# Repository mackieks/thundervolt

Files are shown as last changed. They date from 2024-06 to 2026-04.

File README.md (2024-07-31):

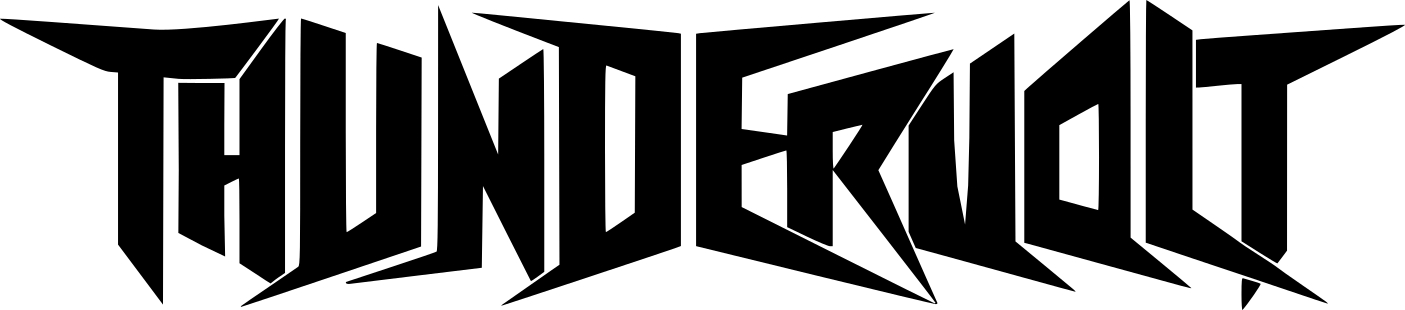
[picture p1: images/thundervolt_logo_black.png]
<picture> <source media="(prefers-color-scheme: dark)" srcset="images/thundervolt_logo_white.png">  </picture> 

Thundervolt is a suite of open-source hardware and software that enables software-configurable undervolting of 4-layer Wiis. 

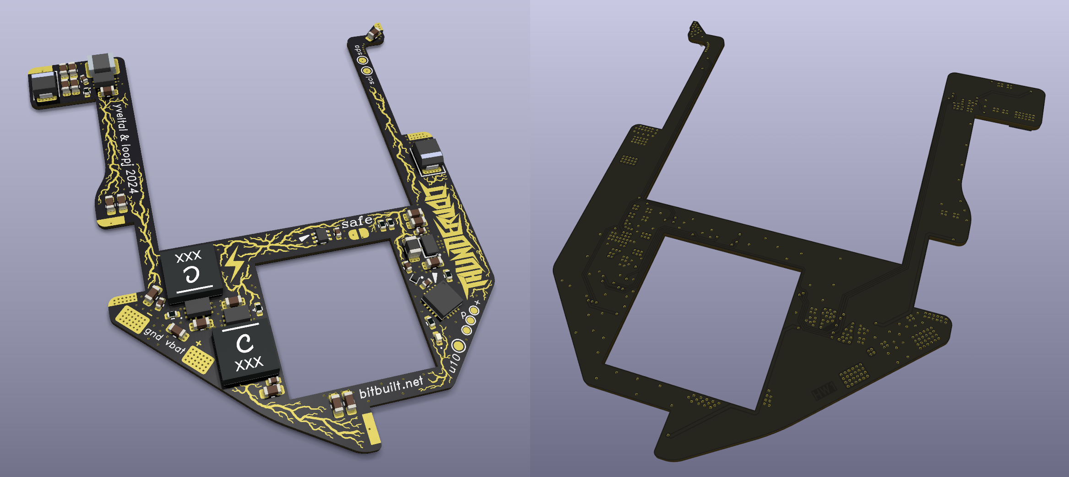
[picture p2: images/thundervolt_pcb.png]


The Thundervolt PCBs (Thundervolt 1 and Thundervolt Lite shown) are stylish, highly-integrated power hats for 4-layer Wiis that solder directly to the Wii motherboard. Only 3 wires are necessary to connect Thundervolt to the Wii (I2C and Reset). Power is supplied via two additional wires.

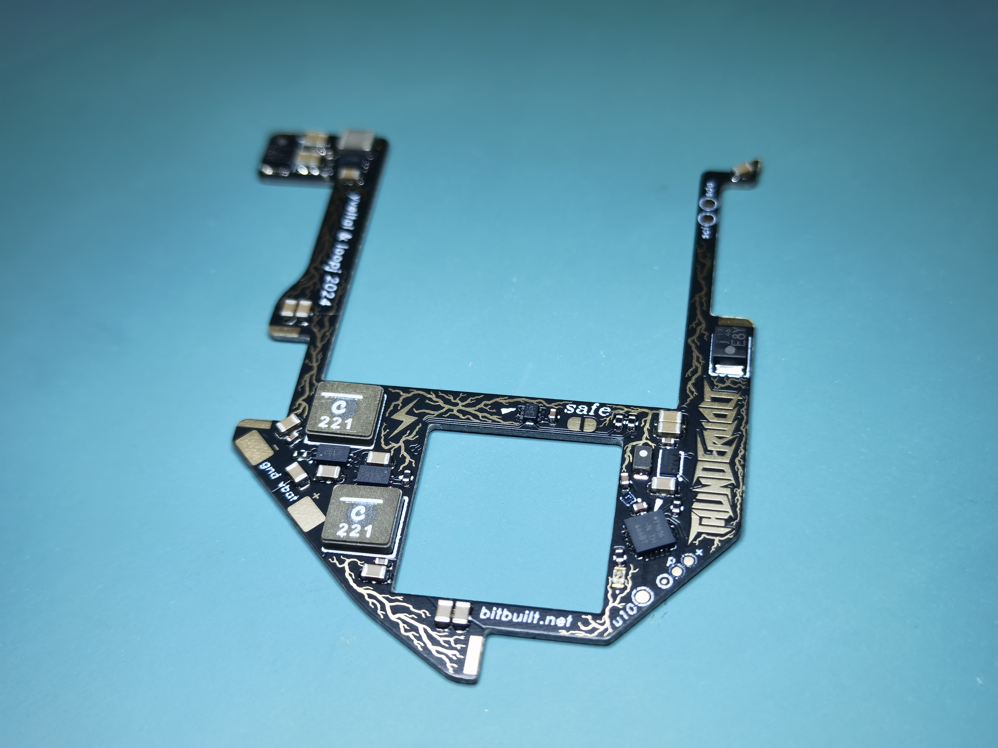
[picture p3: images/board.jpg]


The Thundervolt homebrew app (Dolphin debug version shown) provides granular control over each voltage regulator on the Thundervolt board, as well as emergency overtemperature protection with a configurable threshold. 

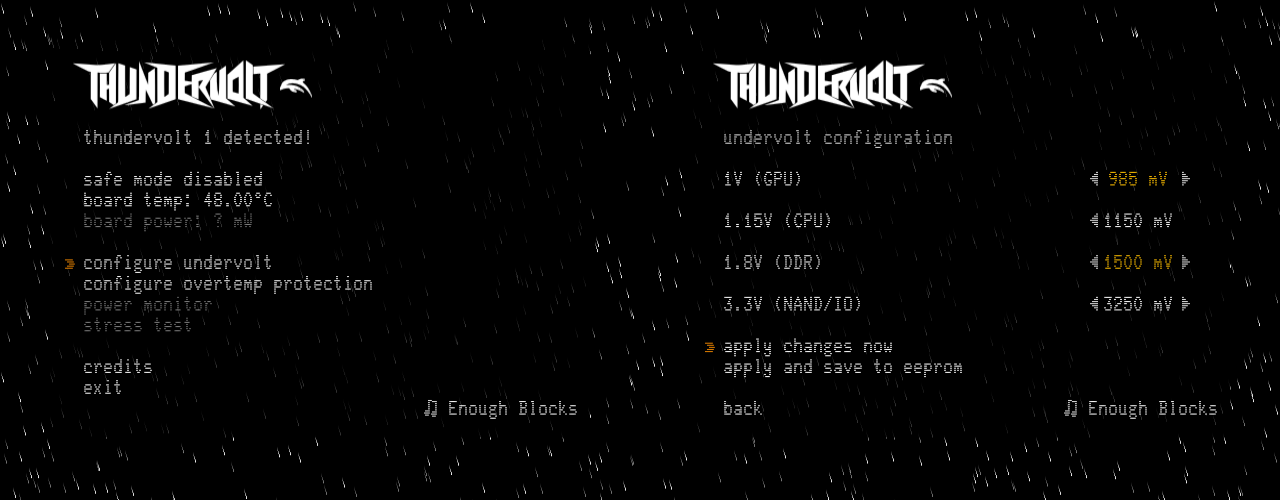
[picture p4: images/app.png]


Users can apply changes live, and save settings to Thundervolt's EEPROM for persistence across reboots. 

More functionality such as CPU/GPU/MEM stress tests and a power monitor for Thundervolt 2 will be added to the app in the future.

## Features
- 0.8mm 4L rigid PCB — solders directly to 4-layer Wii motherboards
- 55 x 47mm — fits within all but the most extreme trim outlines
- 2.4V to 5.5V input (intended for 1S li-ion or 5V USB-C)
- Highly efficient I2C-controlled buck regulators for 1V, 1.15V, and 1.8V (η > 90%)
- Highly efficient I2C-controlled buck-boost regulator for 3.3V (η > 90%)
- Dynamic undervolting, configurable via Wii homebrew app
- Safe mode solder jumper to force stock voltages
- Wii power-on reset functionality (aka U10 emulation)
- Onboard TMP1075N for temperature monitoring and emergency overtemp shutdown
- Integrated INA700s for realtime voltage/current/power monitoring (Thundervolt 2 only)

## What Thundervolt does NOT do
- Battery management and charging
- Fan control
- Power button handling for portables
- USB PD negotiation

Adding a full BMS to Thundervolt would require major sacrifices to regulator efficiency, thermal performance, and cost. A companion board called *Mjolnir* is in development to fulfill these needs, and will feature tight integration with the existing Thundervolt ecosystem.

## Ordering & Assembly

See [the hardware folder](https://github.com/mackieks/thundervolt/tree/main/hardware) for details on ordering and [assembling](https://github.com/mackieks/thundervolt/blob/main/hardware/ASSEMBLY.md) Thundervolt PCBs.

## Usage
The homebrew app is pretty self explanatory; see [the demo on YouTube](https://youtu.be/DeZFMLoE9EQ) for details. A full writeup will come later.

## Credits

Thundervolt hardware designed by YveltalGriffin

Thundervolt firmware by loopj

Thundervolt homebrew by:
- YveltalGriffin (UI, app)
- loopj (I2C, app)
- Alex/supertazon (graphics)
- ShockSlayer (music)

## License

Thundervolt hardware is licensed under Solderpad Hardware License v2.1.

Thundervolt software (firmware + homebrew) is provided under The MIT License.

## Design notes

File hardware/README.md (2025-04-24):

<picture> <source media="(prefers-color-scheme: dark)" srcset="../images/thundervolt_logo_white.png">  </picture> 

There are 3 variants of the Thundervolt PCB. As of 2024-07-07, **Thundervolt Lite** and **Thundervolt 1** have been released.
- **Thundervolt Lite**
  - A low cost revision of the original design with **identical functionality** to Thundervolt 1. It does not require VIPPO and only costs $7 for 10 bare boards!
  - Thundervolt Lite is easier to assemble and easier to solder to the Wii motherboard.
  - Fully tested and released to the public! This folder contains the KiCAD source and Gerbers.
- **Thundervolt 1**
  - The original design, with software-controlled undervolting and temperature sensing. It requires a [VIPPO/POFV PCB](https://jlcpcb.com/blog/32-Free-Via-in-Pad-on-6-20-Layer-PCBs-with-POFV) which is rather expensive ($10 per bare board).
  - Fully tested and released to the public! This folder contains the KiCAD source and Gerbers.
- **Thundervolt 2**
  - The Lamborghini of Wii voltage regulation. Thundervolt 2 includes four INA700 power monitor ICs and can report the Wii's current and power consumption in real time. It requires an even higher spec PCB than Thundervolt 1 and is quite expensive ($14-$20 per bare board)
  - Currently unreleased — still in testing

- All Thundervolt revisions require placing and reflowing at least one chipscale BGA (the TPS63810 3.3V buck-boost regulator). 
- Thundervolt 1 and 2 require placing and reflowing an additional chipscale part (LP5907UVX-1.8, 0.7x0.7mm) and have tighter component spacing than Lite. 
- Thundervolt 2 also requires placing four additional chipscale BGAs (INA700, 1.2x1.3mm)
- Thundervolt Lite is the easiest to assemble. Thundervolt 1 is tougher, and Thundervolt 2 is the most challenging. Magnification is highly recommended for assembling all variants.

Two jig PCBs for solderpaste stenciling are also provided. Order both jigs as 2-layer 0.8mm boards.



## Ordering PCBs

### Thundervolt Lite

Recommended board fabrication specs for **Thundervolt Lite** (JLCPCB).

**MANDATORY**
- 0.8mm 4-layer rigid PCB
- Tented or plugged vias
- Min via hole size/diameter: leave at default. Thundervolt Lite has large vias that do not incur additional charges.

Optional
- ENIG (improves solderability for chipscale BGAs)
- 1oz/in² copper on internal layers - not necessary, but technically improves PDN performance (imperceptible to end user)
- Black soldermask - not necessary, but looks great with the lightning bolt art :)

In the **Remark** section of your Thundervolt Lite PCB order, paste the following comment:
```
Kindly note that the graphics on the fMask layer are for aesthetics. Please do NOT edit any of the fMask apertures on the board, or remove any thin soldermask webs. Thank you!
```

If JLC tries to upcharge you for the soldermask artwork, push back. The artwork requires zero additional work or intervention on their part. Feel free to reference my Thundervolt Lite order number if necessary: **Y118-2549677A**

### Thundervolt 1

Recommended board fabrication specs for **Thundervolt 1** (JLCPCB). Thundervolt 1 is a high-spec PCB. Please read this entire section so you understand the fab requirements. 

**MANDATORY**
- 0.8mm 4-layer rigid PCB
- Epoxy Filled & Capped vias (aka VIPPO or POFV)
- Min via hole size/diameter: 0.15mm/(0.25/0.3mm)

Optional
- ENIG (improves solderability for chipscale BGAs)
- 1oz/in² copper on internal layers - not necessary, but technically improves PDN performance (imperceptible to end user)
- Black soldermask - not necessary, but looks great with the lightning bolt art :)

In the **Remark** section of your Thundervolt 1 PCB order, paste the following comment:
```
Kindly note that the graphics on the fMask layer are for aesthetics. Please do NOT edit any of the fMask apertures on the board, or remove any thin soldermask webs. Thank you!
```

If JLC tries to upcharge you for the soldermask artwork, push back. The artwork requires zero additional work or intervention on their part. Feel free to reference my Thundervolt 1 order number if necessary: **Y108-2549677A**

**Note:** Check the box for **Confirm Production File**. Then check the box for "Do Not Confirm Automatically." JLCPCB will often edit the gerbers in unpleasant ways and you **must** push back on this. If they change the via drill sizes, you need to request that they abide by their listed spec of 0.15mm drills. 

A comment like this when reviewing the production file goes a long way:
```
In the production file, the via drill size has been changed from 0.15mm to 0.2mm [or whatever they changed it to]. Please do not change the via size. They should be 0.15mm drill and 0.3mm diameter as in the original file. I greatly appreciate your assistance with this. Thanks!
```

Some amount of "compensation" (growth of annular rings + padshaving) is unavoidable; however, if the drills are increased to 0.2mm or more, this will result in extreme padshaving of many vias/traces. You'll also notice that they expand the copper clearance around drills on inner layers as part of the compensation process. As long as they are not changing the drill diameters, this is OK. They may also request to remove annular rings ("pads") on internal layers. This is OK as it lessens the impact of their copper clearance expansion on the inner planes.



## Stencil and Jig

Both an electropolished solder paste stencil and the two jig PCBs (jig1, jig2) are **highly** recommended for assembly. 

**MANDATORY STENCIL SPECS**
- Custom dimensions: **90 x 90mm**
- Top only
- Electropolishing

Order both jig1 and jig2 as 0.8mm 2-layer PCBs. In the **Remark** section of both jig PCB orders, paste the following comment:
```
Please note that this is a mechanical PCB and does not contain any drill holes or soldermask openings. Thank you!
```

## BOM

**Thundervolt Lite:** [Link to Mouser cart with BOM](https://www.mouser.com/ProjectManager/ProjectDetail.aspx?AccessID=3CC491924A) [Link to Digikey cart with BOM](https://www.digikey.com/en/mylists/list/P9BJON8540)

**Thundervolt 1**: [Link to Mouser cart with BOM](https://www.mouser.com/ProjectManager/ProjectDetail.aspx?AccessID=D2F0182832)

**Note:** The 0412CDMCCDS-R22MC low-profile inductors used on Thundervolt Lite are only available [from Digikey.](https://www.digikey.com/en/products/detail/sumida-america-inc/0412CDMCCDS-R22MC/11682034)

**Note:** The XFL5015-221MEC low-profile inductors used on Thundervolt 1 and Thundervolt 2 are only available [directly from Coilcraft.](https://www.coilcraft.com/en-us/products/power/shielded-inductors/molded-inductor/xfl/xfl501x/xfl5015-221/)

## Assembly

See [ASSEMBLY.md](https://github.com/mackieks/thundervolt/blob/main/hardware/ASSEMBLY.md) for assembly instructions.

## License

Thundervolt hardware was designed by YveltalGriffin and is licensed under Solderpad Hardware License v2.1.

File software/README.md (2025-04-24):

# Thundervolt Software

Firmware and homebrew for Thundervolt.

Pre-built binaries for the firmware, and packages for the homebrew can be found in the [releases](https://github.com/mackieks/thundervolt/releases) section.

## Firmware

The Thundervolt firmware is written in AVR C with no external dependencies. We use [PlatformIO](https://platformio.org/) to build and flash the firmware, providing a consistent build environment and an easy way to manage toolchains.

### Prerequisites

- [PlatformIO Core](https://platformio.org/install) installed.
- UPDI programmer (e.g., [ATMEL-ICE](https://www.microchip.com/en-us/development-tool/atatmel-ice), [Adafruit UPDI Friend](https://www.adafruit.com/product/5879), [SerialUPDI](https://www.tindie.com/products/mcudude/serialupdi-programmer/)).

### Building

To build the firmware using PlatformIO, enter the `firmware` directory and run:

```bash
pio run -e thundervolt-hw1
```

This will automatically download the required toolchain and build the firmware.

If you are using VS Code, you can build the firmware by opening the `firmware` folder in VS Code. Let the PlatformIO extension configure the project. Select the correct environment to match your board variant. Then click the Build button at the bottom (check mark icon).

### Flashing

Flashing the firmware requires a UPDI programmer. You can use the official [ATMEL-ICE](https://www.microchip.com/en-us/development-tool/atatmel-ice), or a cheaper programmer such as the [Adafruit UPDI Friend](https://www.adafruit.com/product/5879) or MCUdude's [SerialUPDI](https://www.tindie.com/products/mcudude/serialupdi-programmer/).

You need to change line 12 of `platformio.ini` to match the programmer you're using.

- `atmelice_updi` for ATMEL-ICE
- `serialupdi` for SerialUPDI or UPDI Friend

Then click the Upload button in VS Code. 

To flash the firmware directly using PlatformIO, run:

```bash
pio run -e thundervolt-hw1 -t upload
```

Ensure your UPDI programmer is connected before running the command or clicking the Upload button! All Thundervolt board variants have the same programming pad pinout, but you'll need to reference your specific programmer's docs for its pinout. 

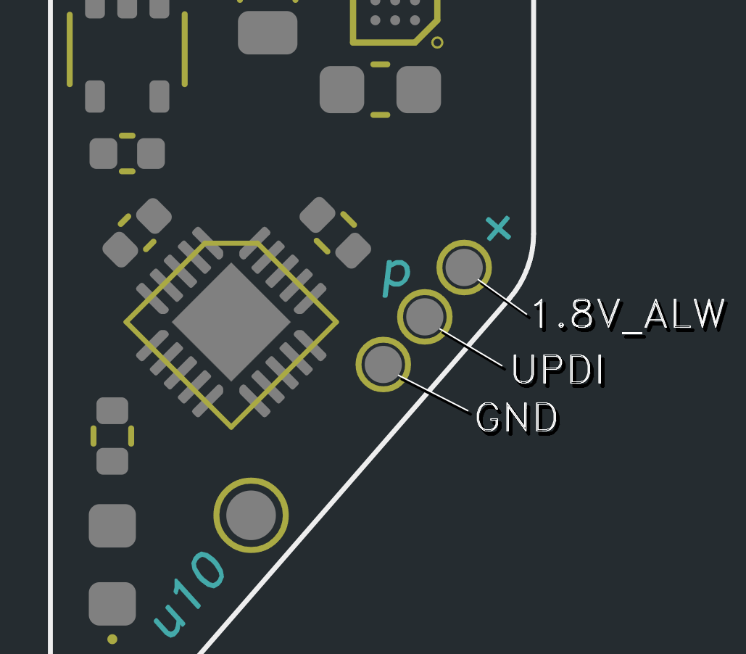
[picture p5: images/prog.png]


The Thundervolt board must be powered from a 2.5V - 5.5V supply for programming to succeed! See [ASSEMBLY.md](https://github.com/mackieks/thundervolt/blob/main/hardware/ASSEMBLY.md) for details.

## Homebrew

The Thundervolt homebrew is a standard Wii homebrew, built with [devkitPro](https://devkitpro.org/). It depends on [GRRLIB](https://github.com/GRRLIB/GRRLIB).

### Prerequisites

- [devkitPro](https://devkitpro.org/wiki/Getting_Started) installed.
- [GRRLIB](https://github.com/GRRLIB/GRRLIB) installed.

### Building

To build the homebrew, enter the `homebrew` directory and run:

```bash
make
```

This will create a `thundervolt.dol` file.

### Packaging

To build a zip package of homebrew and assets, run:

```bash
make dist
```

The zip package will be created in the `dist` directory.

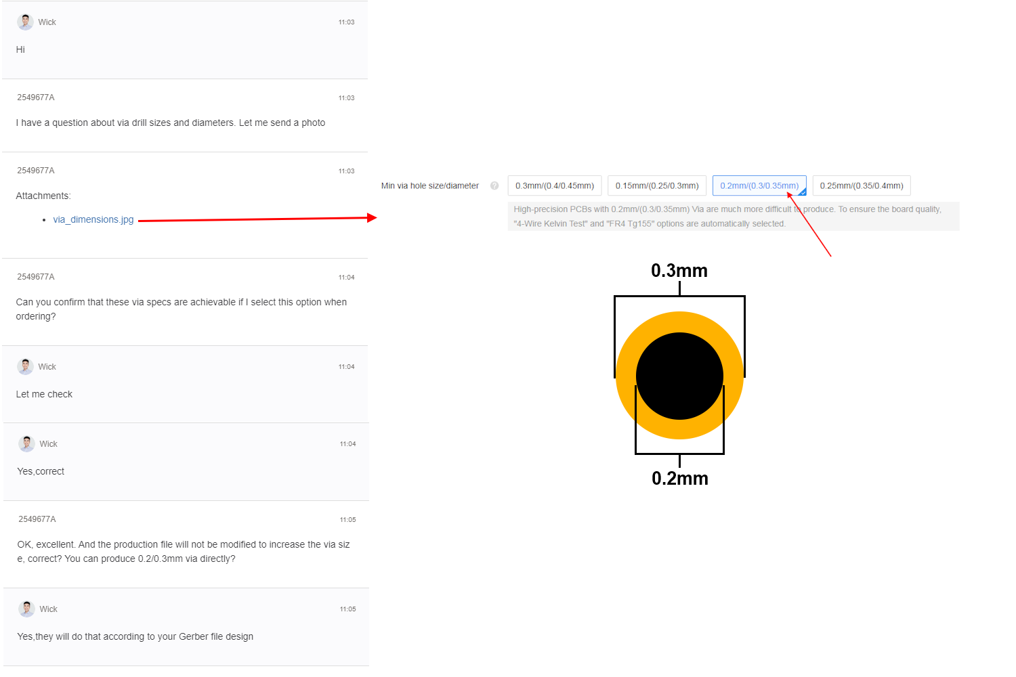
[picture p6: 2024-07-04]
images/jlc_support.png

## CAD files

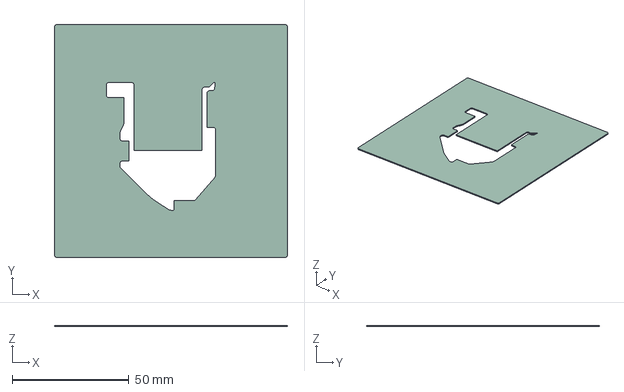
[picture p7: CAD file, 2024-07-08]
hardware/KiCad/jig1/jig1.step
100.0 x 100.0 x 0.6 mm

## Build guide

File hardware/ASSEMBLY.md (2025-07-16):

# Assembly

## Supplies & Equipment

Before assembling a Thundervolt, you should have the following supplies:
- Thundervolt PCB
- Two jig PCBs (outer and inner)
- Electropolished solderpaste stencil
- Solder paste
  - Recommendations: [TS391AX](https://www.mouser.com/ProductDetail/Chip-Quik/TS391AX?qs=1mbolxNpo8ei%252BndH51pRbA%3D%3D) (leaded), [GC50](https://www.digikey.com/en/products/detail/loctite/2591111/12570372) (lead-free)
- Solder paste spreader
  - Recommendation: [SS-METAL-0.2-68X36](https://www.mouser.com/ProductDetail/Chip-Quik/SS-METAL-0.2-68X36?qs=By6Nw2ByBD2Amr8PPfSm%252Bg%3D%3D)
- [Fine tweezers](https://www.mouser.com/ProductDetail/Apex-Tool-Group/EROP3SA?qs=AGa1uUH1LDimyk4IzeBO0g%3D%3D) or a vacuum pen ([Pixel Pump](https://shop.robins-tools.com/products/pixel-pump-starter-kit), [Pick+](https://shop.randomhacks.pt/products/pick)) for component placement
- Reflow method
  - Hot plate: [UYUE 946-1010 or UYUE 946C  ](https://www.aliexpress.us/item/3256804722742113.html)
  - Reflow oven: [Controleo3](https://whizoo.com/collections/controleo3)
  - Hot air is **not** recommended for assembly as it will blow the chipscale BGAs away!
- Hot air station ([1](https://www.aliexpress.us/item/3256801112464148.html), [2](https://www.aliexpress.us/item/2255800796511424.html)), soldering iron ([1](https://pine64.com/product/pinecil-smart-mini-portable-soldering-iron/), [2](https://www.aliexpress.com/i/3256802537430044.html), [3](https://hakkousa.com/fx-951-soldering-station.html)) for rework
- Tacky flux for rework ([SMD291](https://www.mouser.com/ProductDetail/Chip-Quik/SMD291?qs=8BX3xQzFIvmwkympZqnNNA%3D%3D), [MG Chem 8341](https://www.mouser.com/ProductDetail/MG-Chemicals/8341-10ML?qs=SUQPjvP5usWRLDN27VlqNg%3D%3D), [AMTECH NC-559-V2](https://shop.inventec.dehon.com/products/copie-de-amtech-nc-559-v2), [CitriFlow](https://www.injuredgadgets.com/tcrs-citriflow-tm-no-clean-tacky-flux-paste-w-needle-and-cover-10g-syringe/))

Nice-to-haves:
- [Magnetic surface](https://www.ebay.com/itm/186036507277) to stencil on
- Nd magnets and double-sided tape for stenciling
- [91% isopropyl alcohol](https://www.ebay.com/itm/363216561079) for cleaning
- [Kimwipes](https://www.mouser.com/ProductDetail/MG-Chemicals/830-34155?qs=WXzVXFlun0Vx2RYSUZAAsA%3D%3D)
- [Ultrasonic cleaner](https://www.amazon.com/VEVOR-Commercial-Ultrasonic-Capacity-Solution/dp/B01HGNM5WE)
- Magnification is **strongly** recommended
  - [Magnifying Lamp](https://www.amazon.com/Brightech-LightView-PRO-Magnifying-Magnification/dp/B016LTTS8S/)
  - [Amscope 7x-45x](https://www.ebay.com/itm/140938262240)

## Assembly

Once you have everything you need, you can begin stenciling. Apply some double-sided tape to the back of the outer jig PCB.

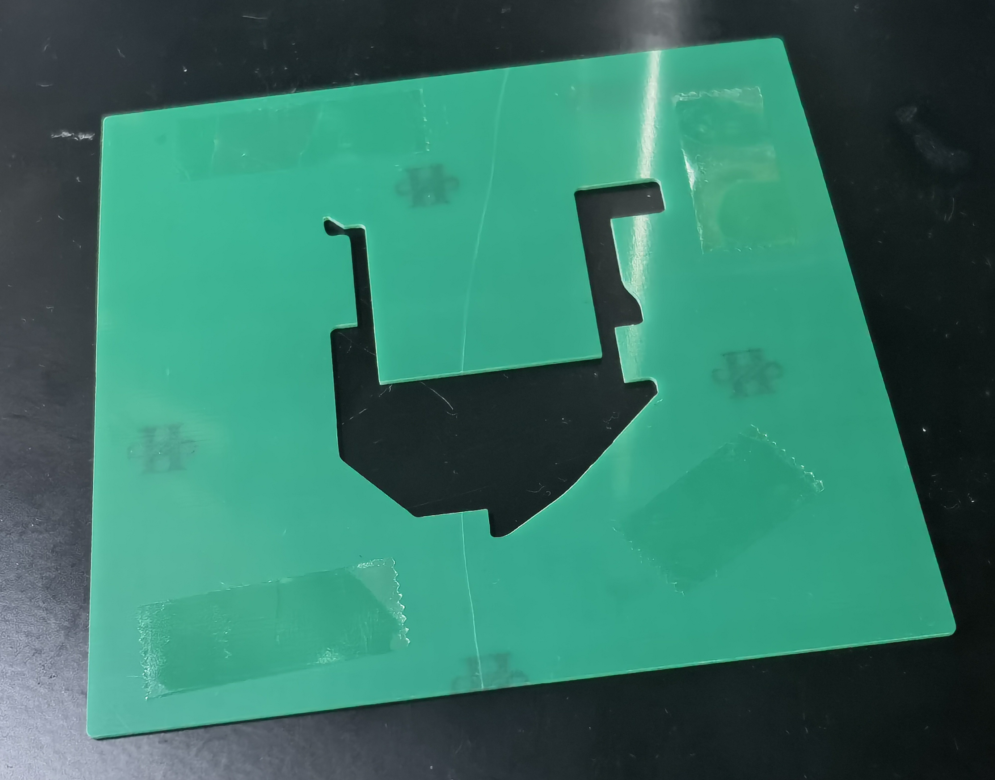
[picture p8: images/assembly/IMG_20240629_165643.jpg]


Adhere the jig to your stenciling surface.

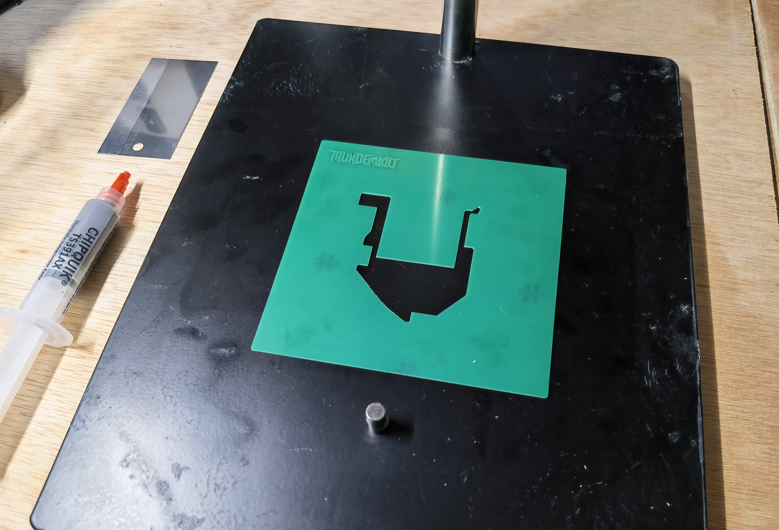
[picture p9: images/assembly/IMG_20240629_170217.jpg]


Prep the Thundervolt PCB by cleaning it with isopropyl alcohol. Then insert the Thundervolt PCB and inner jig into the outer jig.

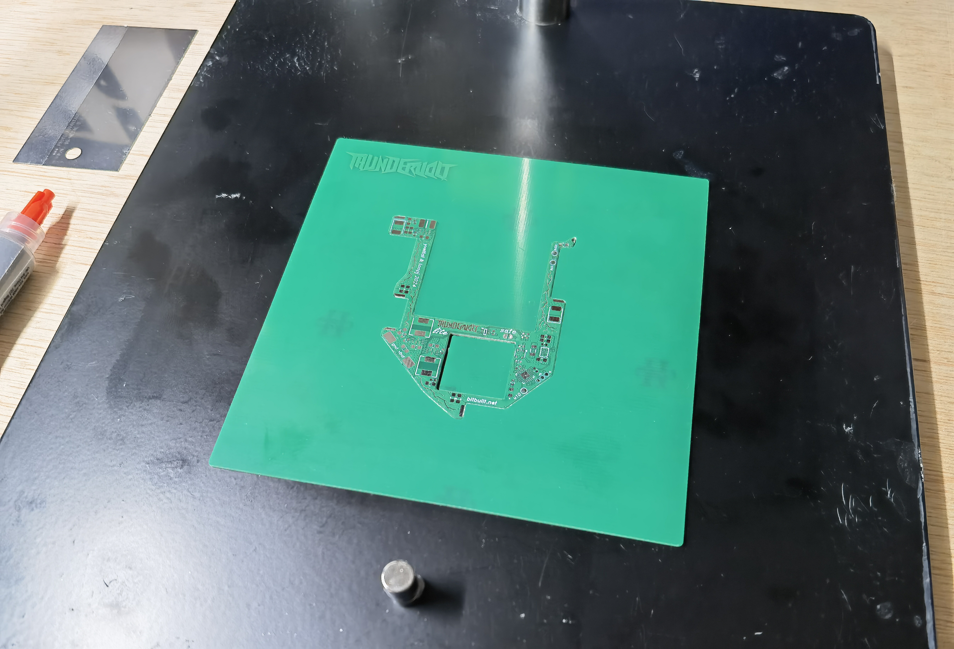
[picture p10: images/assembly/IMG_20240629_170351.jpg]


Prep the stencil by cleaning it with isopropyl alcohol.

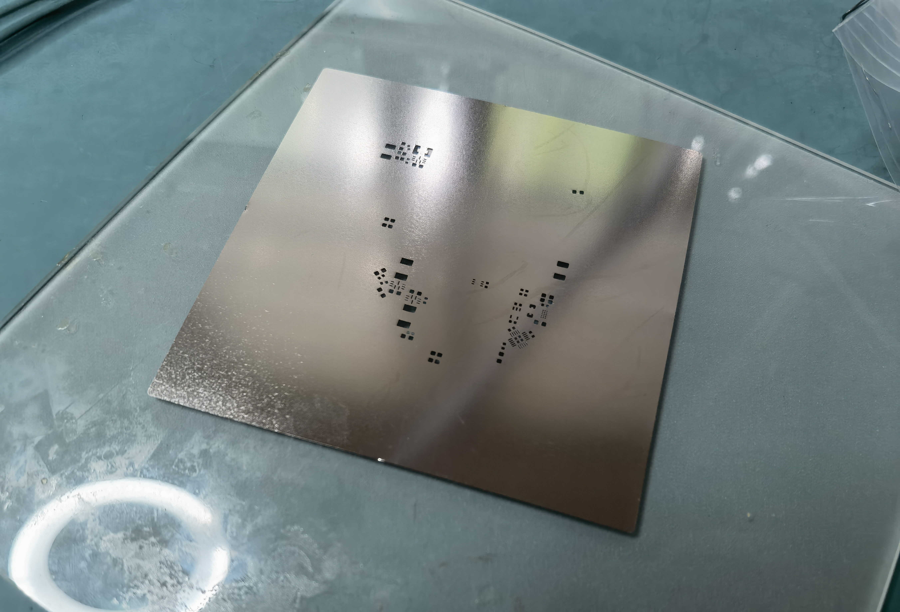
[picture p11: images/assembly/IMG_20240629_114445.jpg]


Align the stencil with the Thundervolt PCB. Make sure the stencil apertures align perfectly with the exposed pads on the board— good lighting is critical here. Use some tape at the top edge of the stencil to secure it in place and act as a hinge. If you are using a magnetic stenciling surface, you can place some strong magnets on the edges of the stencil to keep it flush.

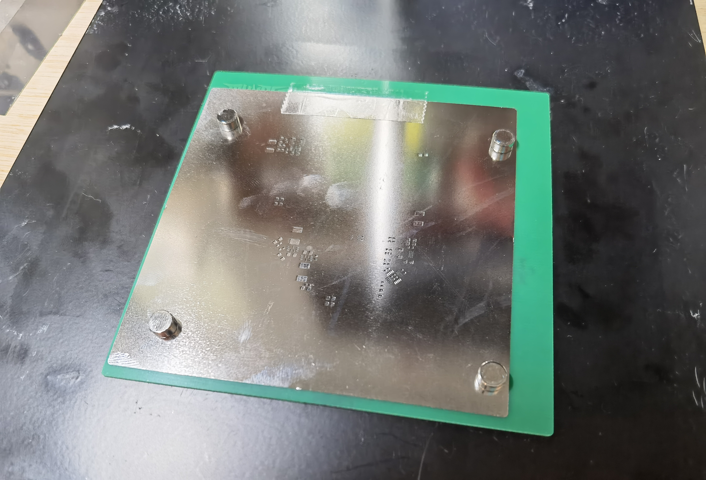
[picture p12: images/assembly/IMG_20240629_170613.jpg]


Dispense some solderpaste in a line across the top edge of the stencil and squeegee it downward. There are many tutorials for stenciling on YouTube if you need additional guidance.

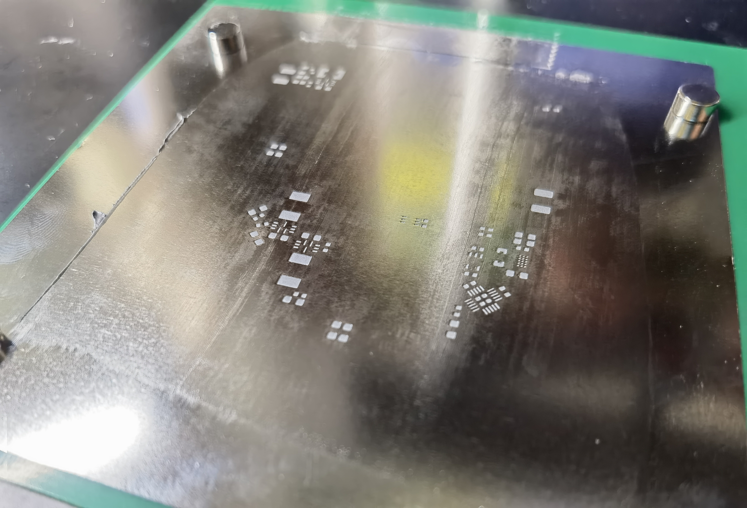
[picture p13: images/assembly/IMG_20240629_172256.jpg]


Carefully slide the magnets off the stencil and peel it up. The cleaner your pasting and stencil release, the less rework you will have to perform after reflow. It's worth retrying the process a couple times to get it right.

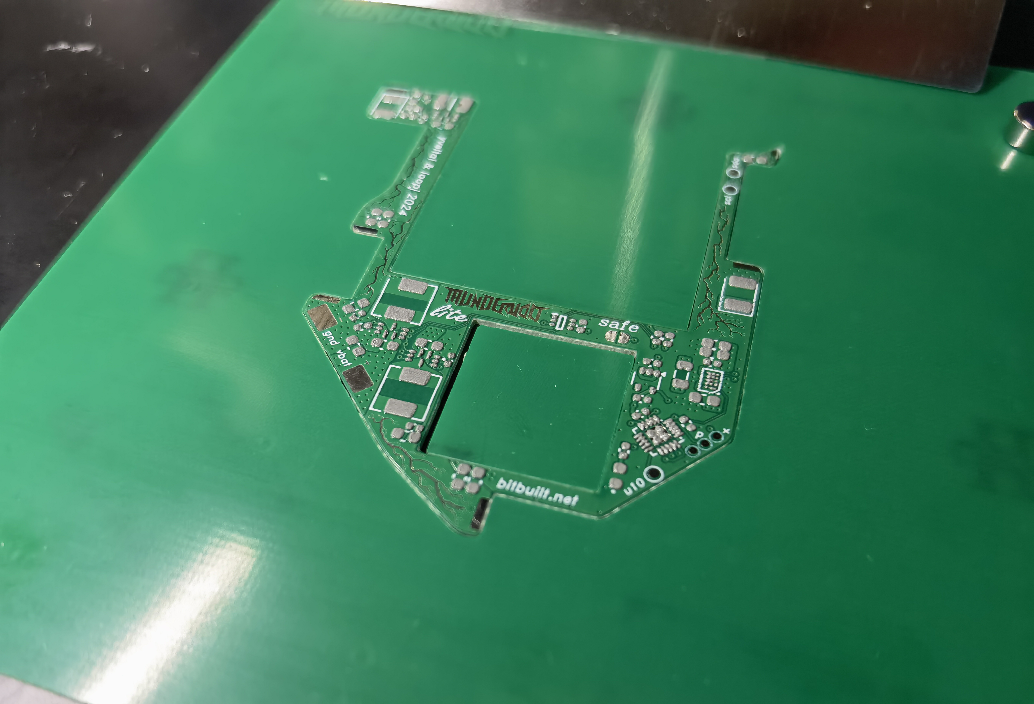
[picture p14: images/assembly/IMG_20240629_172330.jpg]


Open the BOM.html file for your Thundervolt variant in a web browser and place all the components with tweezers or a vacuum pen.



Reflow the PCBA. A hot plate works well for one-offs. Otherwise, use a reflow oven. Hot air is **not** recommended for reflow as it tends to blow the chipscale BGAs away.

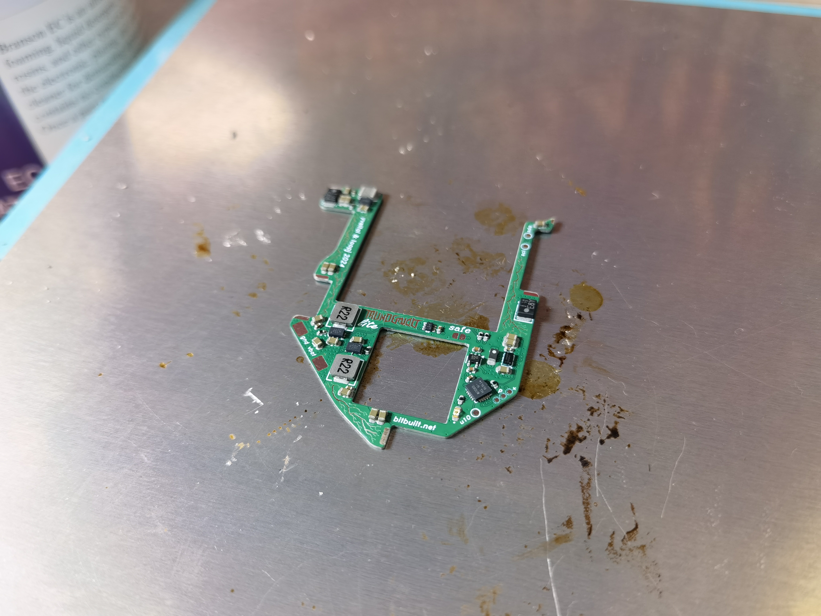
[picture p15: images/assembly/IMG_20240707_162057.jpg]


## Rework

You may need to perform rework on your Thundervolt board, especially if your board was sitting out for a long time, or your pasting job was messy (both of which were true for this example assembly!) Inspect the board for any misaligned or tombstoned components, and any head-in-pillow defects. Any free-floating solder balls should also be removed.



Drowning components in tacky flux and reflowing them with hot air solves most issues. Sometimes you need to remove a component, re-tin the pads on the PCB with your iron, and reflow the part back on. 

After rework, clean off all flux residue with Kimwipes and 91% isopropyl or an ultrasonic cleaner. Inspect all the solder joints, especially on the voltage regulators and BGAs. 





Check for shorts between GND and the following nets: VBAT, 1.8V_ALW, LX1/LX2 on the 3.3v regulator, and the output rails. Also check for shorts between EN (non-GND side of R7) and VBAT/LX1/LX2/3.3V. (LX1 and LX2 are the two pins of L4.)

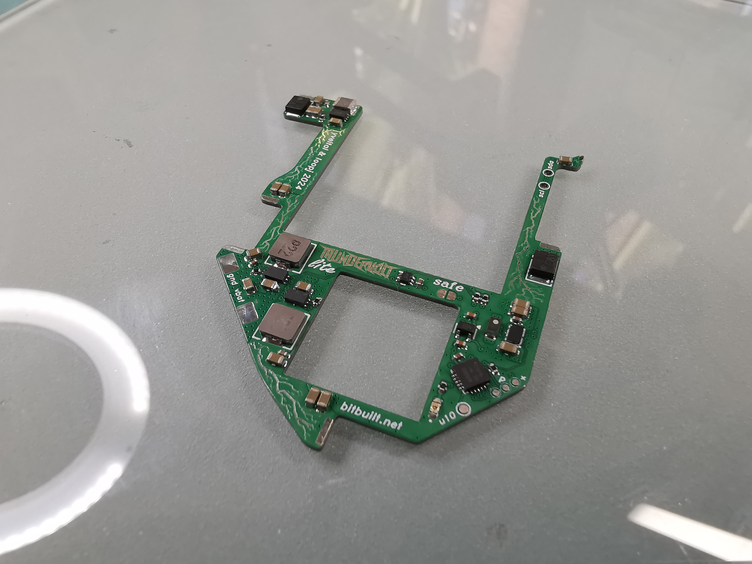
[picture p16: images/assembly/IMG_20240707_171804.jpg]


## Bring-Up

Once the board is fully assembled and cleaned, you can flash it. Congrats!



Thundervolt must be powered from the VBAT and GND pads in order to be flashed! Connect a 2.5V - 5.5V supply (or 1S li-ion battery) to VBAT and GND. Measure voltage between 1.8V_ALW and GND at the programming pads to confirm the LDO is outputting 1.8V.

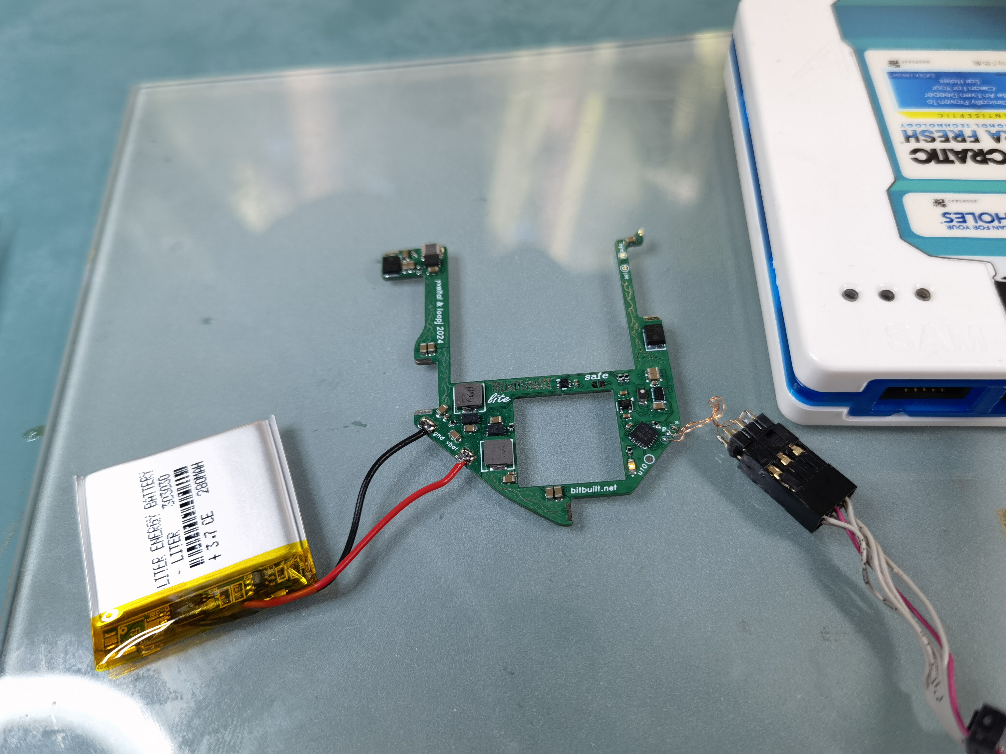
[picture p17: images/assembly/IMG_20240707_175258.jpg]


Now you can connect your programmer to the programming pads and flash the latest Thundervolt firmware. Be sure to build and flash the firmware matching your board type.

All board variants have the same programming pad layout. Reference your programmer's docs for its pinout.



See the [software folder](https://github.com/mackieks/thundervolt/tree/main/software) for more details on building and flashing the firmware.

## Troubleshooting

Once the firmware is flashed, Thundervolt automatically does a self-test.  If everything is OK, the amber LED will pulse slowly (breathing pattern). If the ATtiny cannot talk to all of the regulators and the temperature sensor over I2C, it will turn off the regulators and flash the amber LED with an SOS pattern. This indicates an assembly issue on the board.

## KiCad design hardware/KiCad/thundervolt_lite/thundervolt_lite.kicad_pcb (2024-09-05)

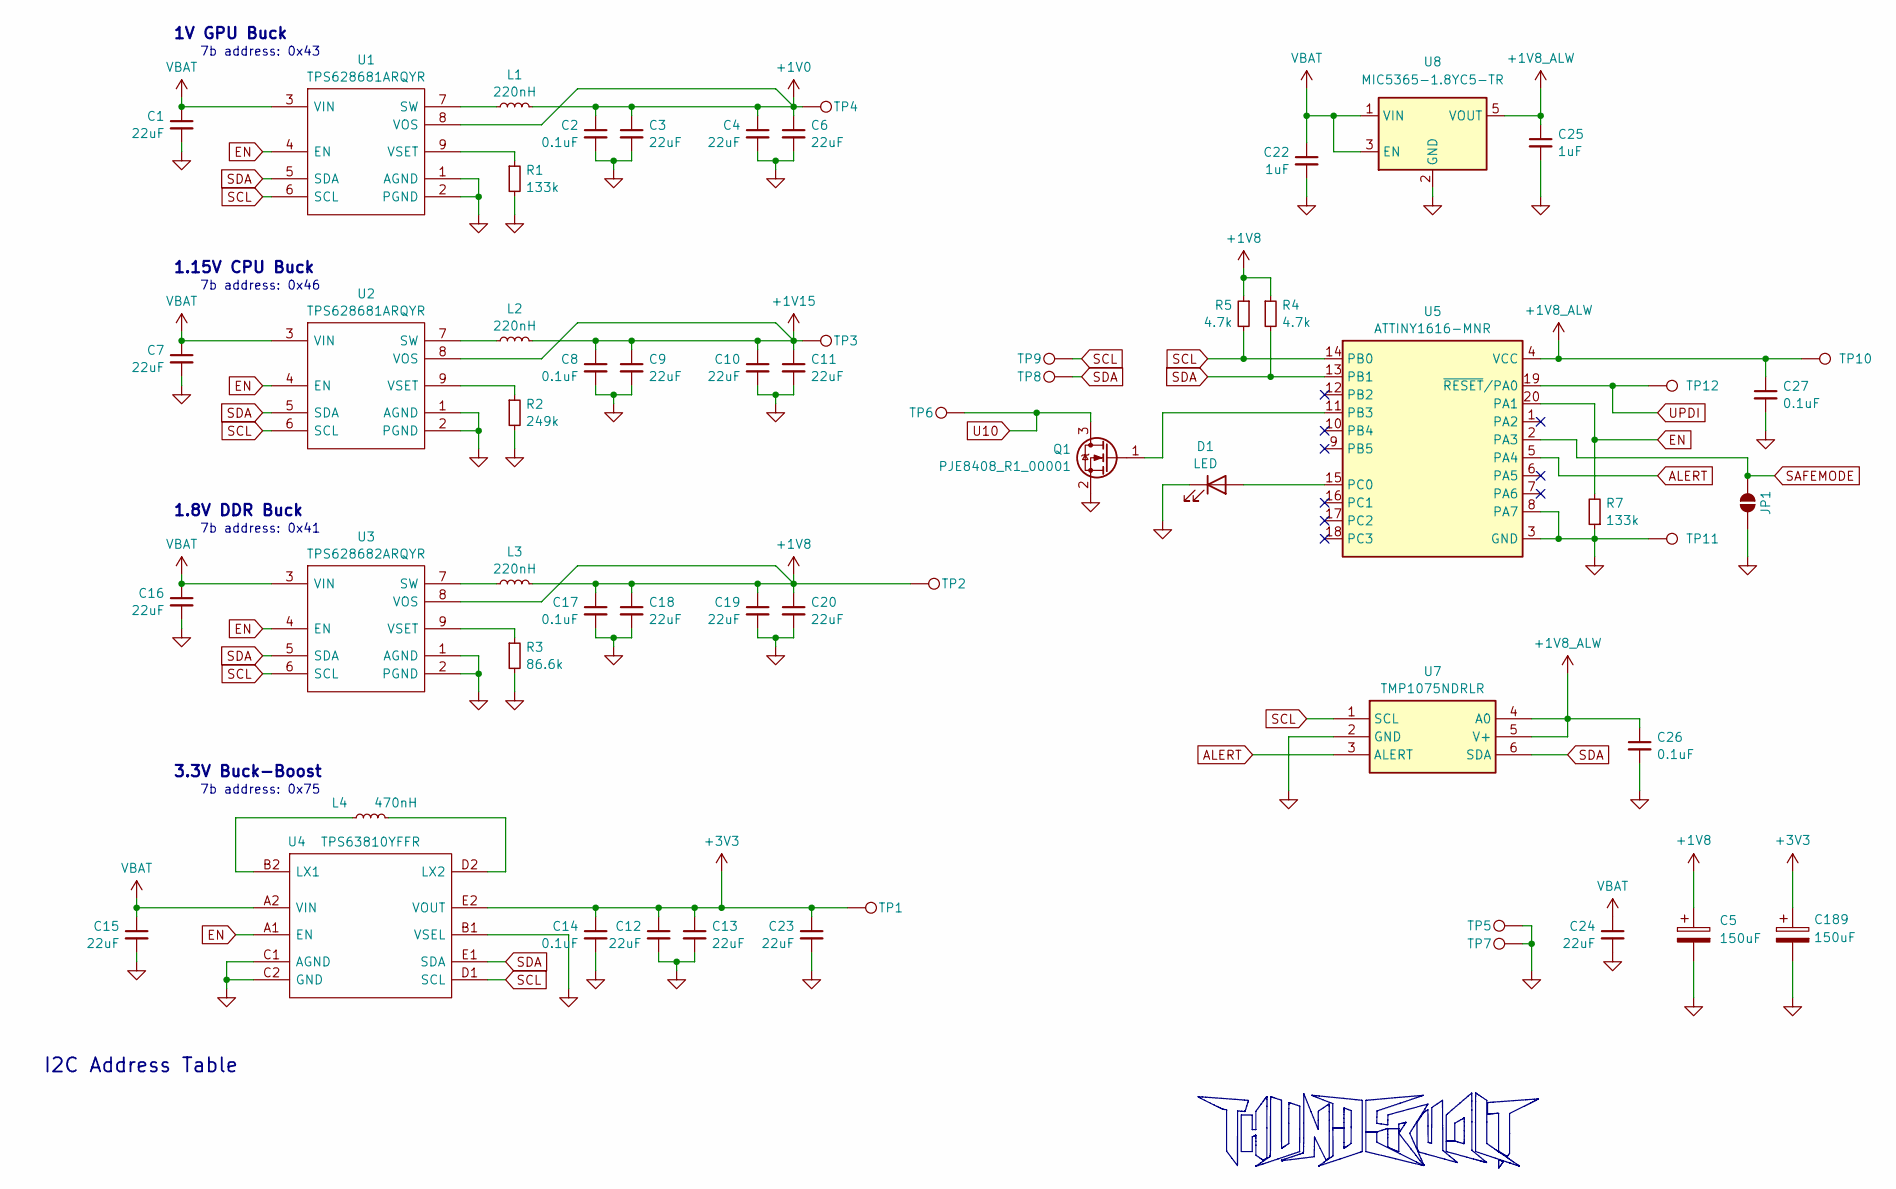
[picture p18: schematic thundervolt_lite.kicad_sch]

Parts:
C1, C3, C4, C6, C7, C9, C10, C11, C12, C13, C15, C16, C18, C19, C20, C23, C24: 22uF; C_0603_1608Metric
C2, C8, C14, C17, C26, C27: 0.1uF; C_0402_1005Metric
C5, C189: 150uF; CP_EIA-3528-15_AVX-H
C22, C25: 1uF; C_0402_1005Metric
D1: LED; LED_0603_1608Metric
JP1: SolderJumper_2_Open; SolderJumper-2_P1.3mm_Open_RoundedPad1.0x1.5mm
L1, L2: 220nH; 0412CDMCCDS-R22MC
L3: 220nH; INDC3225X120N
L4: 470nH; L_0805_2012Metric
Q1: PJE8408_R1_00001; SOT-523
R1, R7: 133k; R_0402_1005Metric
R2: 249k; R_0402_1005Metric
R3: 86.6k; R_0402_1005Metric
R4, R5: 4.7k; R_0402_1005Metric
TP1: 3V3; TestPoint_Pad_1.5x1.0mm
TP2: 1V8; TestPoint_Pad_3x1.0mm
TP3: 1V15; TestPoint_Pad_3x1.0mm
TP4: 1V0; TestPoint_Pad_3x1.0mm
TP5, TP7: GND; TestPoint_Pad_3x1.0mm
TP6, TP8: SDA; TestPoint_Pad_D1.0mm
TP9: SCL; TestPoint_Pad_D1.0mm
TP10: VBAT; TestPoint_Pad_D1.0mm
TP11: GND; TestPoint_Pad_D1.0mm
TP12: UPDI; TestPoint_Pad_D1.0mm
U1, U2: TPS628681ARQYR; TPS628680ARQYR; Mouser Part Number 595-TPS628680ARQYR
U3: TPS628682ARQYR; TPS628680ARQYR; Mouser Part Number 595-TPS628680ARQYR
U4: TPS63810YFFR; BGA15C40P3X5_134X226X62; Mouser Part Number 595-TPS63810YFFR
U5: ATTINY1616-MNR; VQFN-20-1EP_3x3mm_P0.4mm_EP1.7x1.7mm
U7: TMP1075NDRLR; SOTFL50P160X60-6N; Mouser Part Number 595-TMP1075NDRLR
U8: MIC5365-1.8YC5-TR; SOT-353_SC-70-5

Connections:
+1V0: C2.1, C3.1, C4.1, C6.1, L1.2, TP4.1, U1.8 (VOS)
+1V8: C5.1, C17.1, C18.1, C19.1, C20.1, L3.2, R4.1, R5.1, TP2.1, U3.8 (VOS)
+1V8_ALW: C25.1, C26.1, C27.1, TP10.1, U5.4 (VCC), U7.4 (A0), U7.5 (V+), U8.5 (VOUT)
+1V15: C8.1, C9.1, C10.1, C11.1, L2.2, TP3.1, U2.8 (VOS)
+3V3: C12.1, C13.1, C14.1, C23.1, C189.1, TP1.1, U4.E2 (VOUT), U4.E3 (VOUT_2)
ALERT: U5.5 (PA4), U7.3 (ALERT)
EN: R7.2, U1.4 (EN), U2.4 (EN), U3.4 (EN), U4.A1 (EN), U5.20 (PA1)
GND: C1.2, C2.2, C3.2, C4.2, C5.2, C6.2, C7.2, C8.2, C9.2, C10.2, C11.2, C12.2, C13.2, C14.2, C15.2, C16.2, C17.2, C18.2, C19.2, C20.2, C22.2, C23.2, C24.2, C25.2, C26.2, C27.2, C189.2, D1.1 (K), JP1.1 (A), Q1.2 (S), R1.2, R2.2, R3.2, R7.1, TP5.1, TP7.1, TP11.1, U1.1 (AGND), U1.2 (PGND), U2.1 (AGND), U2.2 (PGND), U3.1 (AGND), U3.2 (PGND), U4.B1 (VSEL), U4.C1 (AGND), U4.C2 (GND), U4.C3 (GND_2), U5.3 (GND), U5.8 (PA7), U5.21 (GND), U7.2 (GND), U8.2 (GND)
unnamed: D1.2 (A), U5.15 (PC0)
unnamed: Q1.1 (G), U5.11 (PB3)
unnamed: L1.1, U1.7 (SW)
unnamed: R1.1, U1.9 (VSET)
unnamed: L2.1, U2.7 (SW)
unnamed: R2.1, U2.9 (VSET)
unnamed: L3.1, U3.7 (SW)
unnamed: R3.1, U3.9 (VSET)
unnamed: L4.1, U4.B2 (LX1), U4.B3 (LX1_2)
unnamed: L4.2, U4.D2 (LX2), U4.D3 (LX2_2)
SAFEMODE: JP1.2 (B), U5.2 (PA3)
SCL: R5.2, TP9.1, U1.6 (SCL), U2.6 (SCL), U3.6 (SCL), U4.D1 (SCL), U5.14 (PB0), U7.1 (SCL)
SDA: R4.2, TP8.1, U1.5 (SDA), U2.5 (SDA), U3.5 (SDA), U4.E1 (SDA), U5.13 (PB1), U7.6 (SDA)
U10: Q1.3 (D), TP6.1
UPDI: TP12.1, U5.19 (~RESET/PA0)
VBAT: C1.1, C7.1, C15.1, C16.1, C22.1, C24.1, U1.3 (VIN), U2.3 (VIN), U3.3 (VIN), U4.A2 (VIN), U4.A3 (VIN_2), U8.1 (VIN), U8.3 (EN)

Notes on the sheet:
I2C Address Table
3.3V Buck-Boost
1.15V CPU Buck
7b address: 0x43
7b address: 0x41
1.8V DDR Buck
1V GPU Buck
7b address: 0x75
7b address: 0x46

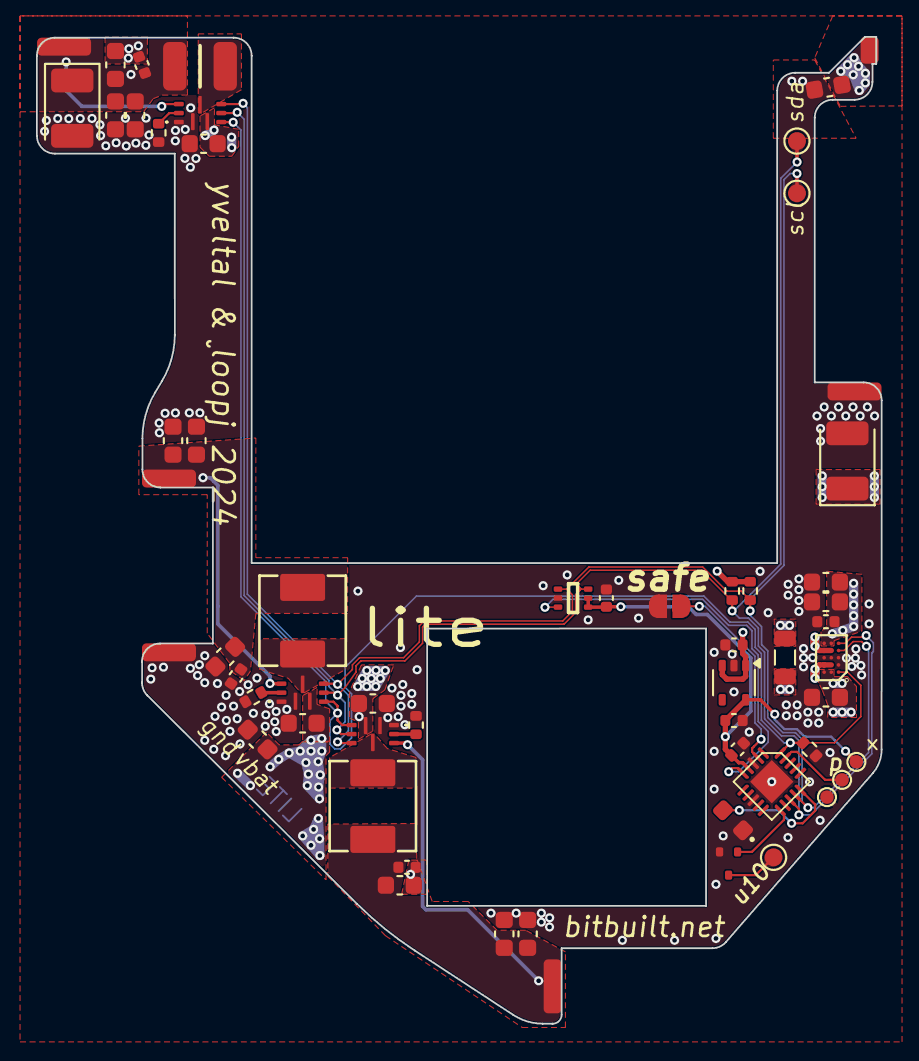
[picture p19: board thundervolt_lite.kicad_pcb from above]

Board: 13 copper layers, 46.9 x 54.8 mm, 59 parts (0 on the bottom side), 24 nets.

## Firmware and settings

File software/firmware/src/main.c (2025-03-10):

#include <stdint.h>
#include <string.h>

#include <avr/eeprom.h>
#include <avr/interrupt.h>
#include <avr/io.h>
#include <util/delay.h>

#include "gpio.h"
#include "i2c.h"
#include "i2c/thundervolt.h"
#include "i2c_target.h"
#include "led.h"

// Device power states
enum device_state { STATE_STANDBY, STATE_POWERED };

// Software revision - increment this for each firmware release
static const uint8_t SOFTWARE_REV = 1;

// GPIO pin definitions
static const gpio_t EN       = {&PORTA, 1};
static const gpio_t SAFEMODE = {&PORTA, 3};
static const gpio_t ALERT    = {&PORTA, 4};
static const gpio_t DIRECT   = {&PORTA, 7};
static const gpio_t U10      = {&PORTB, 3};
static const gpio_t LED      = {&PORTC, 0};

// EEPROM signature, used to detect if the EEPROM has been initialized
static const uint16_t *EEPROM_SIGNATURE_ADDR = 0x00FE;
static const uint16_t EEPROM_SIGNATURE       = 0xCAFE;

// LED effect timings (in milliseconds)
static const uint16_t LED_BREATHE_PERIOD = 2000;
static const uint16_t LED_SOS_PATTERN[]  = {
    200, 200, 200, 200, 200, 600, // S
    600, 200, 600, 200, 600, 600, // O
    200, 200, 200, 200, 200, 1400 // S
};

// RTC millisecond counter
static volatile uint32_t millis = 0;

// Device state
static volatile enum device_state device_state = STATE_STANDBY;

// Register memory space
// For convenience we're also using the same addresses for values persisted in EEPROM
static volatile uint8_t registers[THUNDERVOLT_NUM_REGISTERS];

// Set EEPROM values to their defaults
static void reset_eeprom()
{
  // Write the default CONFIG register value
  eeprom_update_byte(THUNDERVOLT_REG_CONFIG, THUNDERVOLT_LED);

  // Write the default "stock" voltage values
  eeprom_write_word(THUNDERVOLT_REG_VPERS_1V0_L, THUNDERVOLT_STOCK_VOLTAGE_1V0);
  eeprom_write_word(THUNDERVOLT_REG_VPERS_1V15_L, THUNDERVOLT_STOCK_VOLTAGE_1V15);
  eeprom_write_word(THUNDERVOLT_REG_VPERS_1V8_L, THUNDERVOLT_STOCK_VOLTAGE_1V8);
  eeprom_write_word(THUNDERVOLT_REG_VPERS_3V3_L, THUNDERVOLT_STOCK_VOLTAGE_3V3);

  // Write the default over-temperature shutdown temperature
  eeprom_update_byte(THUNDERVOLT_REG_OTSD_TEMP, THUNDERVOLT_DEFAULT_OTSD_LIMIT);
}

// Initialize the EEPROM if it has never been initialized
static void initialize_eeprom()
{
  // Return early if the EEPROM has already been initialized
  if (eeprom_read_word(EEPROM_SIGNATURE_ADDR) == EEPROM_SIGNATURE)
    return;

  // Write the default "stock" voltage values
  reset_eeprom();

  // Write the signature
  eeprom_write_word(EEPROM_SIGNATURE_ADDR, EEPROM_SIGNATURE);
}

// Check if the specified register is read-only
static inline bool is_read_only_register(uint8_t reg_addr)
{
  return reg_addr == THUNDERVOLT_REG_STATUS || reg_addr == THUNDERVOLT_REG_HWREV || reg_addr == THUNDERVOLT_REG_SWREV;
}

// Get the value of a 16-bit register
static inline uint16_t get_word_register(uint8_t addr)
{
  return registers[addr] | (registers[addr + 1] << 8);
}

// Populate the registers with persistent values from the EEPROM
static void load_persisted_registers()
{
  for (uint8_t i = 0; i < THUNDERVOLT_NUM_REGISTERS; i++) {
    if (is_read_only_register(i))
      continue;

    registers[i] = eeprom_read_byte((uint8_t *)i);
  }
}

// Initialize the registers to their "reset" state
static void reset_registers()
{
  // Initialize the register space to 0
  memset(registers, 0, THUNDERVOLT_NUM_REGISTERS);

  // Initialize the fixed registers
  registers[THUNDERVOLT_REG_HWREV] = THUNDERVOLT_HWREV;
  registers[THUNDERVOLT_REG_SWREV] = SOFTWARE_REV;

  // Populate the registers with persistent values from EEPROM
  load_persisted_registers();
}

// Handle register reads from an I2C controller when in I2C target mode
static int handle_register_read(uint8_t reg_addr, uint8_t *value)
{
  // Return 0x00 for out-of-bounds register reads
  if (reg_addr >= THUNDERVOLT_NUM_REGISTERS) {
    *value = 0x00;
    return -1;
  }

  // Read the register value
  *value = registers[reg_addr];

  return 0;
}

// Handle register writes from an I2C controller when in I2C target mode
static int handle_register_write(uint8_t reg_addr, uint8_t value)
{
  // Ignore writes to read-only registers and out-of-bounds registers
  if (is_read_only_register(reg_addr) || reg_addr >= THUNDERVOLT_NUM_REGISTERS)
    return -1;

  // Handle CONFIG register writes
  if (reg_addr == THUNDERVOLT_REG_CONFIG) {
    // Handle the CLEAR bit
    if (value & THUNDERVOLT_CLEAR) {
      // Clear persisted registers
      reset_eeprom();
      load_persisted_registers();

      // We just cleared CONFIG, so load the updated value
      value = registers[THUNDERVOLT_REG_CONFIG];
    }

    // Handle the LED bit
    if (value & THUNDERVOLT_LED) {
      led_effect_breathe(LED_BREATHE_PERIOD);
    } else {
      led_off();
    }
  }

  // Update the register
  registers[reg_addr] = value;

  // Persist the value to the EEPROM
  // for some reason eeprom_update_byte is buggy, so use eeprom_update_byte instead
  eeprom_update_byte((uint8_t *)reg_addr, value);

  return 0;
}

// Initialize the GPIO pins
static void gpio_init()
{
  // Safe mode jumper, active low (when bridged)
  gpio_input(SAFEMODE);
  gpio_config(SAFEMODE, PORT_PULLUPEN_bm);

  // Temperature sensor alert pin, active low
  gpio_input(ALERT);
  gpio_config(ALERT, PORT_PULLUPEN_bm | PORT_ISC_FALLING_gc);

  // Regulator enable pin, active high
  gpio_output(EN);
  gpio_set_low(EN);

  // Pinstrapping to detect U10 Direct Mode vs FET Mode
  gpio_input(DIRECT);
  gpio_config(DIRECT, PORT_PULLUPEN_bm);

  // Check pinstrapping to see if board has U10 FET
  bool u10_direct_mode = gpio_read(DIRECT);

  // U10 emulation pin
  gpio_output(U10);

  // Assert U10 (make it low)
  if (u10_direct_mode) {
    gpio_set_low(U10); // faux open-drain (direct mode)
  } else {
    gpio_set_high(U10); // U10 NFET gate is active-high
  }

  // LED, default off
  gpio_output(LED);
  gpio_set_low(LED);
}

// Initialize the RTC for periodic interrupts
void rtc_init()
{
  RTC.CLKSEL     = RTC_CLKSEL_INT32K_gc;
  RTC.PITINTCTRL = RTC_PI_bm;
  RTC.PITCTRLA   = RTC_PERIOD_CYC32_gc | RTC_PITEN_bm;
}

// Handle periodic RTC interrupts (every ~1ms)
ISR(RTC_PIT_vect)
{
  // Clear the interrupt flag
  RTC.PITINTFLAGS = RTC_PI_bm;

  // Update the "milliseconds since boot" counter
  millis++;

  // Update the LED effect
  led_effect_update(millis);
}

// Handle gpio interrupts on PORTA
ISR(PORTA_PORT_vect)
{
  // Handle the temperature sensor alert
  if (gpio_read_intflag(ALERT)) {
    // Shutdown the regulators if over-temp shutdown is enabled
    if (device_state == STATE_POWERED && registers[THUNDERVOLT_REG_CONFIG] & THUNDERVOLT_OTSD) {
      // Disable the regulators
      gpio_set_low(EN);

      // Enable the SOS LED effect
      led_effect_blink_pattern(LED_SOS_PATTERN, sizeof(LED_SOS_PATTERN) / sizeof(LED_SOS_PATTERN[0]));
    }
  }

  // Clear the interrupt flags
  PORTA.INTFLAGS = 0xFF;
}

int main(void)
{
  // Enable prescaler, and set prescaler division to 4 to run at 5MHz
  CPU_CCP           = CCP_IOREG_gc;
  CLKCTRL.MCLKCTRLB = CLKCTRL_PDIV_4X_gc | CLKCTRL_PEN_bm;

  // Set I2C target interrupts as the highest priority
  CPUINT.LVL1VEC = TWI0_TWIS_vect_num;

  // Enable interrupts (for I2C target comms and overtemp alerting)
  sei();

  // Initalize the GPIOs
  gpio_init();

  // Initialize the RTC
  rtc_init();

  // Initialize the LED
  led_init();

  // Initialize as an I2C controller
  i2c_configure(I2C_MODE_STANDARD);

  // uncomment for forced EEPROM reset (debug)
  // reset_eeprom();

  // Initialize the EEPROM with stock values if it has never been initialized
  initialize_eeprom();

  // Initialize the registers to their "reset" state
  reset_registers();

  // Check if we are in safe mode
  bool in_safe_mode = !gpio_read(SAFEMODE);
  if (in_safe_mode) {
    registers[THUNDERVOLT_REG_STATUS] |= THUNDERVOLT_SAFEMODE;
  }

  // Registers cannot be read/written via I2C on the TPS62868x until startup is finished,
  // so we must enable the regulators and wait a short time (at least ~1100us) first
  gpio_set_high(EN);
  _delay_ms(3);

  // Make sure we can talk to all four regulators and the TMP. If not, shut down + enable SOS until power is cycled
  if (!thundervolt_i2c_scan()) {

    gpio_set_low(EN);

    // Enable the SOS LED effect
    led_effect_blink_pattern(LED_SOS_PATTERN, sizeof(LED_SOS_PATTERN) / sizeof(LED_SOS_PATTERN[0]));

    asm volatile("nop"); // required due to some sinister bug somewhere...
    while (1);
  }

  // Determine the startup voltages
  uint16_t voltages[4];
  if (in_safe_mode) {
    // Use stock voltage values
    voltages[THUNDERVOLT_RAIL_1V0]  = THUNDERVOLT_STOCK_VOLTAGE_1V0;
    voltages[THUNDERVOLT_RAIL_1V15] = THUNDERVOLT_STOCK_VOLTAGE_1V15;
    voltages[THUNDERVOLT_RAIL_1V8]  = THUNDERVOLT_STOCK_VOLTAGE_1V8;
    voltages[THUNDERVOLT_RAIL_3V3]  = THUNDERVOLT_STOCK_VOLTAGE_3V3;
  } else {
    // Use persisted voltage values
    voltages[THUNDERVOLT_RAIL_1V0]  = get_word_register(THUNDERVOLT_REG_VPERS_1V0_L);
    voltages[THUNDERVOLT_RAIL_1V15] = get_word_register(THUNDERVOLT_REG_VPERS_1V15_L);
    voltages[THUNDERVOLT_RAIL_1V8]  = get_word_register(THUNDERVOLT_REG_VPERS_1V8_L);
    voltages[THUNDERVOLT_RAIL_3V3]  = get_word_register(THUNDERVOLT_REG_VPERS_3V3_L);
  }

  // Set the voltage on each regulator
  for (uint8_t i = THUNDERVOLT_RAIL_1V0; i <= THUNDERVOLT_RAIL_3V3; i++) { thundervolt_set_voltage(i, voltages[i]); }

  // Set the over-temperature limit based on the persisted value
  thundervolt_set_otsd_limit(registers[THUNDERVOLT_REG_OTSD_TEMP]);

  // Wait 200ms to emulate the U10 delay
  _delay_ms(200);

  // Check pinstrapping to see if board has U10 FET
  bool u10_direct_mode = gpio_read(DIRECT);

  // Deassert U10 (make it high-impedance) so Hollywood can boot
  if (u10_direct_mode) {
    gpio_input(U10); // faux open-drain (direct mode)
  } else {
    gpio_set_low(U10); // Turn off U10 NFET
  }

  // Update the device state
  device_state = STATE_POWERED;

  // Enable the breathing LED effect if the LED is enabled
  if (registers[THUNDERVOLT_REG_CONFIG] & THUNDERVOLT_LED) {
    led_effect_breathe(LED_BREATHE_PERIOD);
  }

  // Initialize as an I2C target device, and listen for commands
  i2c_target_init(THUNDERVOLT_I2C_ADDR, handle_register_read, handle_register_write);

  // Main loop
  asm volatile("nop"); // required due to some sinister bug somewhere...
  while (1);
}

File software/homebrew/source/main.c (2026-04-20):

/*===========================================
        TrueType Font demo
============================================*/
#include <grrlib.h>

#include <asndlib.h>
#include <mp3player.h>
#include <ogc/pad.h>
#include <stdio.h>
#include <stdlib.h>
#include <wiiuse/wpad.h>

#include "i2c.h"

#include "input.h"
#include "menu.h"
#include "rain.h"

s8 hardwareButton = -1;

void wiiResetPressed(unsigned int irq, void *ctx)
{
  (void)irq;
  (void)ctx;

  hardwareButton = SYS_RETURNTOMENU;
}

void wiiPowerPressed()
{
  hardwareButton = SYS_POWEROFF_STANDBY;
}

void wiimotePowerPressed(s32 chan)
{
  (void)chan;

  hardwareButton = SYS_POWEROFF_STANDBY;
}

int main(int argc, char **argv)
{

  // Initialise the Graphics & Video subsystem
  GRRLIB_Init();

  // Initialise the Wii Remotes
  PAD_Init();
  WPAD_Init();

  ASND_Init();
  MP3Player_Init();

  // Initialize the I2C bus
  i2c_configure(I2C_MODE_STANDARD);

  // Black background
  GRRLIB_SetBackgroundColour(0x00, 0x00, 0x00, 0x00);

  // Set the power and reset callbacks
  SYS_SetResetCallback(wiiResetPressed);
  SYS_SetPowerCallback(wiiPowerPressed);
  WPAD_SetPowerButtonCallback(wiimotePowerPressed);

  // Initialise the rain effect
  setupRain();

  // Initialise the menu
  setupMenu();

  // Loop forever
  while (1) {
    // Fetch the latest input states
    updateInput();

    // Update the menu, and check if it has told us to exit
    bool menuExit = !handleMenuInput();
    if (menuExit)
      break;

    // Draw the rain effect
    drawRain();

    // Draw the menu
    drawMenu();

    // Check if the power or reset button was pressed
    if (hardwareButton != -1)
      break;
  }

  // GRRLIB_FreeTTF(myFont);
  GRRLIB_Exit(); // Be a good boy, clear the memory allocated by GRRLIB

  // Power off or return to the Wii menu
  if (hardwareButton != -1)
    SYS_ResetSystem(hardwareButton, 0, 0);

#if defined(DOLPHIN)
  // Workaround for crash-on-exit bug in Dolphin
  SYS_ResetSystem(SYS_POWEROFF_STANDBY, 0, 0);
#endif

  return 0;
}

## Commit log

2024-07-04 Remove HW2 gerbers and update HW1 gerbers
    [thundervolt-B_Cu.gbr, thundervolt-B_Mask.gbr, thundervolt-F_Mask.gbr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]
2024-07-04 Update gerbers
    [jig1.kicad_pcb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]
2024-07-04 Update hardware filenames
    [jig2.kicad_sch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]
2024-07-08 Add Thundervolt Lite hardware files
    [thundervolt_lite-B_Cu.gbr, thundervolt_lite-B_Mask.gbr, thundervolt_lite-B_Silkscreen.gbr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]
2024-07-08 update board img
2024-07-15 Add assembly images
2024-09-05 U10 FET Mode
    [thundervolt_hw1-B_Cu.gbr, thundervolt_hw1-B_Mask.gbr, thundervolt_hw1-B_Silkscreen.gbr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]
2024-09-05 Update lite gerbers
    [thundervolt_lite-B_Cu.gbr, thundervolt_lite-B_Mask.gbr, thundervolt_lite-B_Silkscreen.gbr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]
2024-12-09 Fix occasional EEPROM write failures
    [thundervolt_hw1.kicad_sch]
2025-03-10 Add power-on self test scan
2025-09-15 Add more detail around i2c bitbang implementation, Zephyr license
2026-04-20 Fix reset SYS_SetResetCallback prototype
    [main.c]
